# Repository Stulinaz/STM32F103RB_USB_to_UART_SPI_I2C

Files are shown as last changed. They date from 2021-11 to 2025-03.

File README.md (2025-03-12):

<!-- For .md file development refers to https://docs.github.com/en -->
# Stm32 Multiprotocol

> [!IMPORTANT]  
> Firmware rework scheduled by end of April 2025.

### Firmware and Kicad project for my USBtoUART/SPI/I2C converter.

Based on the popular microcontroller ***STM32F103RBT6*** and a custom PCB board.
This project is an embedded software/hardawe solutions that allows you to transfer data from USB to all the main digital interfaces - UART, I2C and SPI.
This board will help you to analyze and debug all the main digital and analog IC’s as well as lot of IOT and RF demoboard, saving you the time to develop a custom firmware
, or buying expensive data converters.

## Board Overview

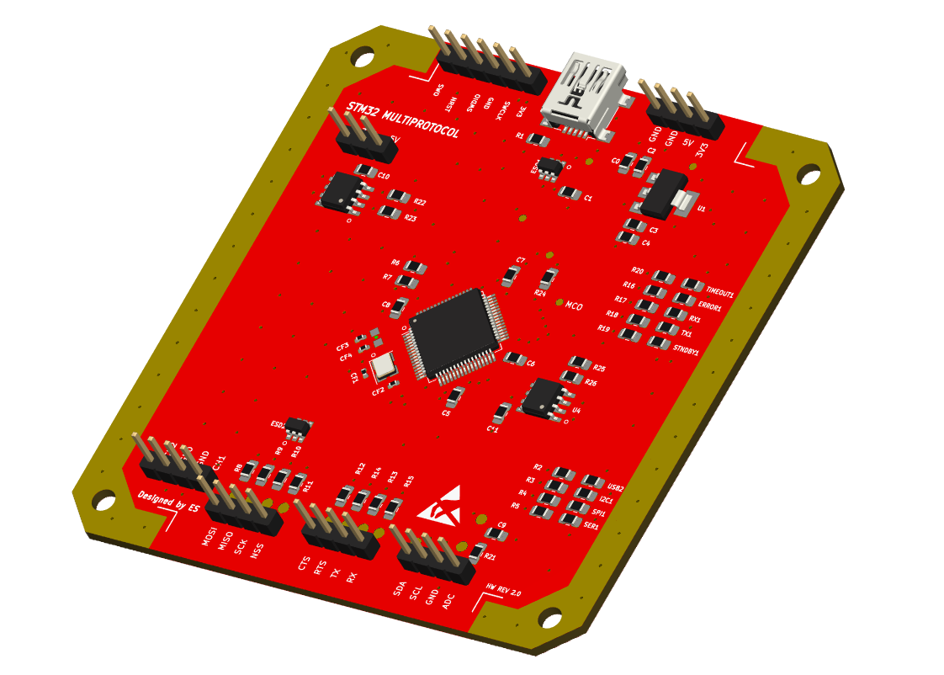
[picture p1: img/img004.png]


## Top Side of the board

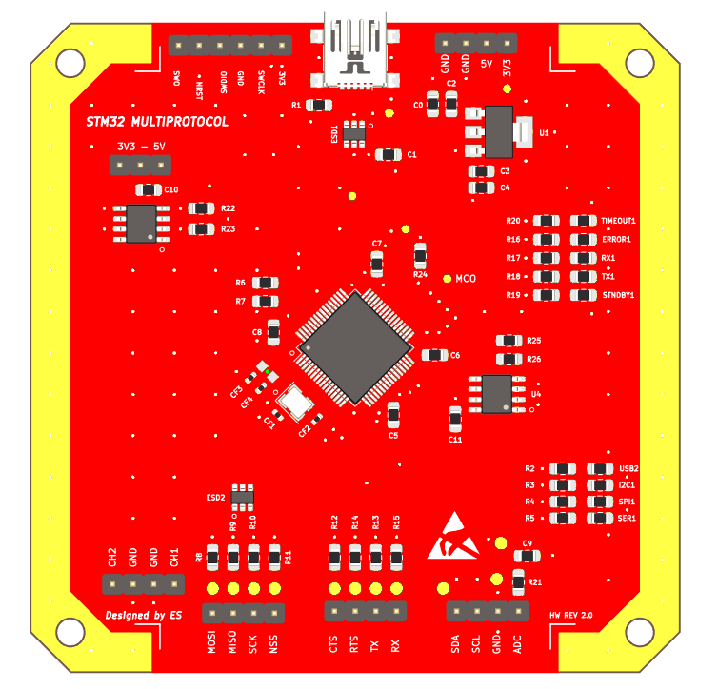
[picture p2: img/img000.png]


## Bottom Side of The board

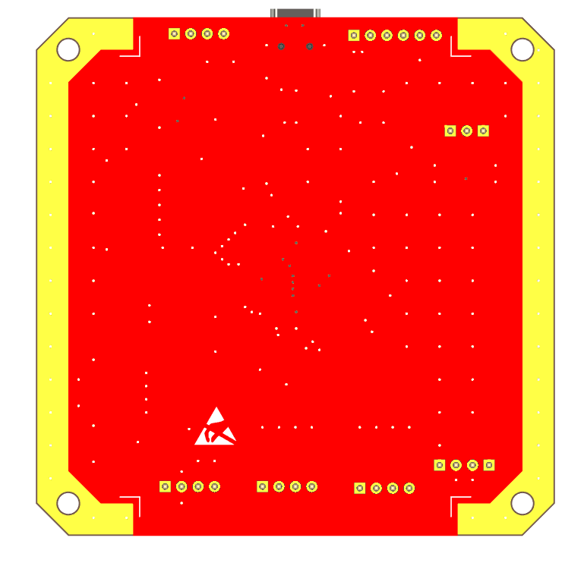
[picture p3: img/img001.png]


## Features 

- SWD Interface.
- Mini USB Connector with ESD protection.
- Power mosfet.
- On board 64k (24C64) eeprom for data storage.

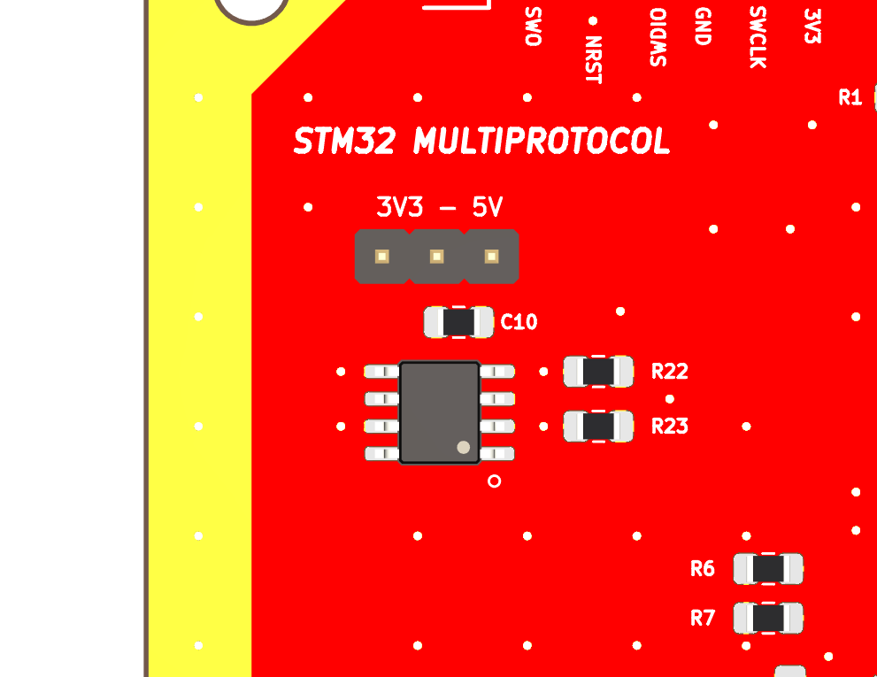
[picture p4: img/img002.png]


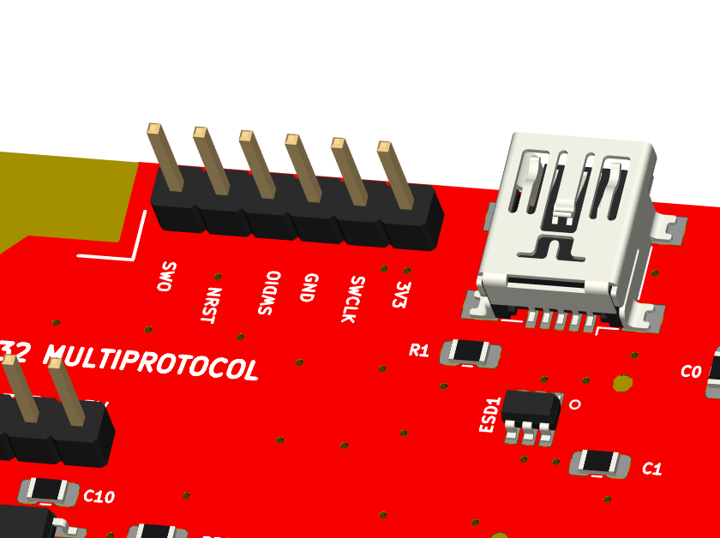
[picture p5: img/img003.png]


## Bill of Materials

| Component  | Description | Part Number | Digy |
|:---  |:--- |:--- |:--- |
| USB1 | CONN RCPT USB2.0 MINI SMD R/A | 0675031020 | [WM5461CT-ND](https://www.digikey.it/it/products/detail/molex/0675031020/1624424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) |
| ESD1 | TVS DIODE 5.25V 17V STO23-6 | USBLC6-2SC6 | [497-5235-6-ND](https://www.digikey.it/it/products/detail/stmicroelectronics/USBLC6-2SC6/1040559) |
| ESD2 | TVS DIODE 5V SOT23-6] | ESDA6V1BC6 | [497-6635-1-ND](https://www.digikey.it/it/products/detail/stmicroelectronics/ESDA6V1BC6/1037985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) |
| U1 | Linear Voltage Regulator IC | IC REG 3.3V 1A | [576-1172-ND](https://www.digikey.it/it/products/detail/microchip-technology/MIC39100-3-3WS/771641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) |
| U2 | ic mcu 32 bit 128kb flash 64LQFP | STM32F103RBT6 | [497-6066-ND](https://www.digikey.it/it/products/detail/stmicroelectronics/STM32F103RBT6/1646341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) |
| Y2 | CRYSTAL 16.0000MHZ 4PF SMD | ABM8W-16.0000MHZ-4-B1U-T3| [535-14020-1-ND](https://www.digikey.it/it/products/detail/abracon-llc/ABM8W-16-0000MHZ-4-B1U-T3/7172791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) |
| U3 | IC GATE DRVR LOW-SIDE 8SOIC | MIC4427ZM | [576-3513-5-ND](https://www.digikey.it/it/products/detail/microchip-technology/MIC4427ZM/1029913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) |
| U4 | IC GATE DRVR LOW-SIDE 8SOIC | M24C64 | [497-14427-1-ND](https://www.digikey.it/it/products/detail/stmicroelectronics/M24C64-DRMN3TP-K/4729231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) | 

## Software needed for development

- [STM32CubeIDE](https://www.st.com/en/development-tools/stm32cubeide.html) **1.17.0**
- [KICAD](https://www.kicad.org/) **8.0.5,release build - 64 bit**
- [GIT](https://git-scm.com/) **2.46.1.windows.1**

## Tools needed for development

Programmer [STLINK](https://www.st.com/en/development-tools/st-link-v2.html)

## Closeup

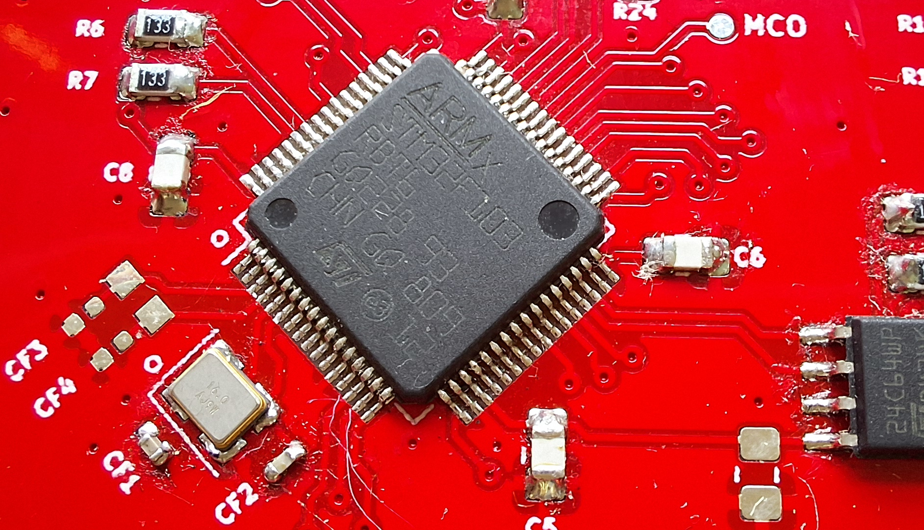
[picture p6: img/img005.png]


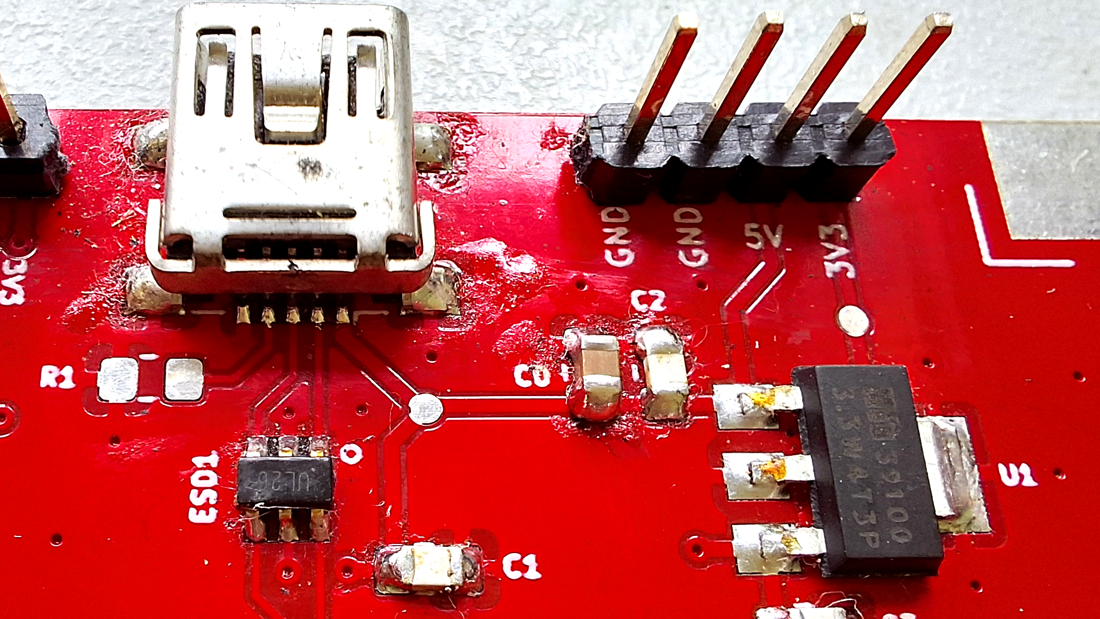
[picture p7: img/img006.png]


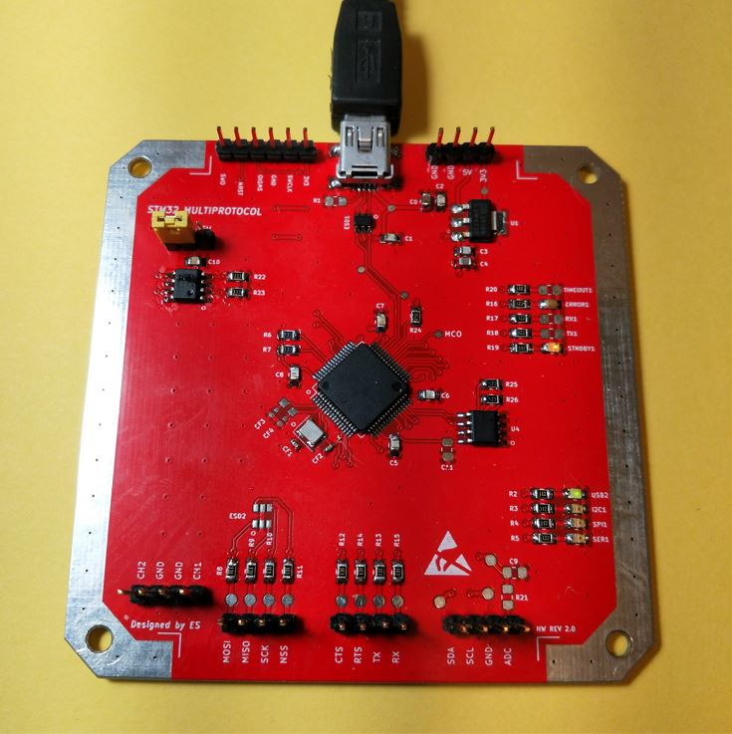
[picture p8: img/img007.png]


## Electrical Characteristics

| **Parameter** | **Min** | **Typ** | **Max** | **Unit** | **Condition/Notes** |
|---|---|---|---|---|---|
| Input Voltage | 4.5 | 5.0 | 5.5 | V | |
| Current Consumption | | 13 | 20 | mA | |

## License

| Component | Copyright | License |
|:--- |:--- |:--- |
| CMSIS | ARM Limited | Apache-2.0 |
| CMSIS Device | ARM Limited - STMicroelectronics | Apache-2.0 |
| STM32WL HAL | STMicroelectronics | BSD-3-Clause |
| FreeRTOS kernel | Amazon.com, Inc. or its affiliates | MIT |
| Stm32 Multiprotocol | N/A | BSD-3-Clause |

## Contact

***enrico.stulin@gmail.com***

[LinkedIn](https://www.linkedin.com/in/enrico-stulin-14090b146/)

## Important Information

> [!CAUTION]
> Manual soldering of SMD components requires high level of manual skills.
> Project not suited for beginners in firmware development.
> A good understanding of C language is a must.

> [!CAUTION]
> This project is provided "AS IS" with no warranties.

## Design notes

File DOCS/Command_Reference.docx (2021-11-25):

Command | Description | NOTE
<stm–h> | Help me! (print all the commands)
<stm–s> | Enables UART interface. Every data will be forwarded to uart interface, enter <stm–a> for closing interface. RESPONSE SUCCESS: “Serial interface selected” RESPONSE INVALID: “unknown command”
<stm–i> | Enables I2C interface. RESPONSE SUCCESS: “I2C interface selected” RESPONSE INVALID: “unknown command”
<stm–p> | Enables SPI interface. Every data will be forwarded to spi interface, enter <imx –a> for closing interface. RESPONSE SUCCESS: “SPI interface selected” RESPONSE INVALID: “unknown command”
<stm–a> | Close the communication interface previosly selected with <stm–s> <stm–i> <stm–p>. RESPONSE SUCCESS: “XXX interface closed” RESPONSE INVALID1: “unknown command”
<stm–testled> | Turns on all on board leds for 10seconds. RESPONSE SUCCESS: “No Response” RESPONSE INVALID1: “unknown command”
<ser–bX> | Baudrate selections for UART interface: X=0 , baudrate 1200 X=1 , baudrate 4800 X=2 , baudrate 9600 X=3 , baudrate 19200 X=4 , baudrate 19200 X=5 , baudrate 19200 X=6 , baudrate 19200 Default or wrong parameter: 9600 RESPONSE SUCCESS: “Serial baudrate set” RESPONSE INVALID1: “unknown command” RESPONSE INVALID2: “Error – interface must be closed”
<spi–nssh> | Set SPI NSS pin active high. Default: NSS active low. RESPONSE SUCCESS: “SPI NSS active high” RESPONSE INVALID1: “unknown command”
<spi–nssl> | Set SPI NSS pin active low. Default: NSS active low. RESPONSE SUCCESS: “SPI NSS active low” RESPONSE INVALID1: “unknown command”
<spi –sX> | Clock speed for spi: X=0 , 6 Mhz X=1 , 3 Mhz X=2 , 1.5 Mhz X=3 , 750 khz X=4 , 357 kHz X=5 , 187 khz X=6 , 93 kHz X=6 , 46 kHz Default or wrong parameter: 46 kHz RESPONSE SUCCESS: “Spi parameter set” RESPONSE INVALID1: “unknown command” RESPONSE INVALID2: “wrong parameter” RESPONSE INVALID2: “Error – interface must be closed”
<spi–cl> | Clock to 0 when idle RESPONSE SUCCESS: “Spi parameter set” RESPONSE INVALID1: “unknown command”
<spi–cl> | Clock to 1 when idle RESPONSE SUCCESS: “Spi parameter set” RESPONSE INVALID1: “unknown command”
<i2c–a0xXX> | Set Slave address. RESPONSE SUCCESS: “Slave Address set” RESPONSE INVALID1: “unknown command”
<i2c–mt> | Generation of Start/repeat start condition + address will be send in write mode. RESPONSE SUCCESS: “Sending address in write mode” RESPONSE INVALID: “unknown command”
<i2c–mr> | Generation of Start/repeat start condition + address will send in read mode. RESPONSE SUCCESS: “Sending address in read mode” RESPONSE INVALID: “unknown command”
<i2c–w0xXX> | Byte Write request. XX value in hexadecimal format [00 – FF] RESPONSE SUCCESS: “Byte write enqueued” RESPONSE INVALID: “unknown command”
<i2c–r> | Byte read request. RESPONSE SUCCESS: “Byte read enqueued” RESPONSE INVALID: “unknown command”
<i2c –q> | Get i2c commands in the queue. RESPONSE SUCCESS: Output the i2c commands queue RESPONSE INVALID: “unknown command”
<i2c –d> | Delete all i2C commands in the queue. SUCCESS: “Queue free” RESPONSE INVALID: “unknown command”
<i2c –x> | Starts i2c transfer. RESPONSE SUCCESS: “Transfer Success” + byte read in HEX format if present. RESPONSE INVALID: “Transfer Failure” + ERROR

REVISION HISTORY
VERSION | REVISION DATE | COMMENTS
1 | 25/22/2021 | First Release

Maker: Stulin Enrico - enrico.stulin@gmail.com – 04/06/2021

STM32 MULTIPROTOCOL

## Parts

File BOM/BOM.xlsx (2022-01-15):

COMPONENT | PART NUMBER | DESCRIPTION | QTY | DIGIKEY ORDER CODE
U1 | MIC39100-3.3WS | Linear Voltage Regulator IC Positive Fixed 1 Output 1A SOT-223-3 | 1 | 576-1172-ND
U2 | STM32F103RBT6 | ic mcu 32 bit 128kb flash 64LQFP | 1 | 497-6066-ND
U3 | MIC4427ZM | IC GATE DRVR LOW-SIDE 8SOIC | 1 | 576-3513-5-ND
U4 | M24C64-DRMN3TP/K | IC EEPROM 64KBIT I2C 1MHZ 8SO | 1 | 497-14427-1-ND
ESD1 | USBLC6-2SC6 | TVS DIODE 5.25V 17V STO23-6 | 1 | 732-1077-1-ND
ESD2 | ESDA6V1BC6 | TVS DIODE 5V SOT23-6 | 1 | 497-6635-1-ND
Y2 | ABM8W-16.0000MHZ-4-B1U-T3 | CRYSTAL 16.0000MHZ 4PF SMD | 1 | 535-14020-1-ND
USB1 | 675031020 | CONN RCPT USB2.0 MINI SMD R/A | 1 | WM5461CT-ND
R1 | CRCW0805100KDHEAP | RES SMD 100K OHM 5% 1/8W 0805 | 1 | 541-100KAZCT-ND
R2, R3, R4, R5, R16, R17, R18, R19, R20 | RMCF0805JT1K00 | RES 1k OHM 5% 1/8W 0805 | 9 | RMCF0805JT1K00CT-ND
R6, R7, R22, R23, R25, R26 | CR0805-JW-103ELF | RES SMD 10k OHM 5% 1/W 0805 | 6 | CR0805-JW-103ELFCT-ND
R8, R9, R10, R11, R12, R13, R14, R15 | CR0805-JW-101ELF | RES SMD 100 OHM 5% 1/W 0805 | 8 | CR0805-JW-101ELFCT-ND
R21 | CR0805-J/-4R7ELF | RES SMD 4.7 OHM 5% 1/8W 0805 | 1 | CR0805-J/-4R7ELF
R24 | CR0805-JW-152ELF | RES SMD 1.5K OHM 5% 1/8W 0805 | 1 | 118-CR0805-JW-152ELFCT-ND
C0, C1, C4, C5, C6, C7, C8, C10, C11 | C0805C101K8RAC7800 | CAP CER 100PF 10V X7R 0805 | 9 | 399-15004-1-ND
C3, C9 | C0805C106K4PAC7800 | CAP CER 10UF 16V X5R 0805 | 2 | 399-C0805C106K4PAC7800CT-ND
C2 | GRM21BR71C105KA01L | CAP CER 1UF 16V X7R 0805 | 1 | 490-1691-1-ND
CF1, CF2 | 04025A3R3BAT2A | CAP CER 3.3PF 50V NP0 0402 | 2 | 478-10103-1-ND
LED GREEN | LG R971-KN-1 | LED GREEN DIFFUSED 0805 SMD | 10 | 475-1410-1-ND
LED RED | LH R974-LP-1-0-20-R18 | LED RED DIFFUSED 0805 SMD | 10 | 475-LHR974-LP-1-0-20-R18CT-ND
LED ORANGE | LO R976-PS-1 | LED ORANGE DIFFUSED 0805 SMD | 10 | LO R976-PS-1
CF3, CF4 | NM | NM | NM | NM
CONNECTORS | 1-87220-0 | CONN HEADER VERT 10POS 2.54MM | 5 | A26556-ND

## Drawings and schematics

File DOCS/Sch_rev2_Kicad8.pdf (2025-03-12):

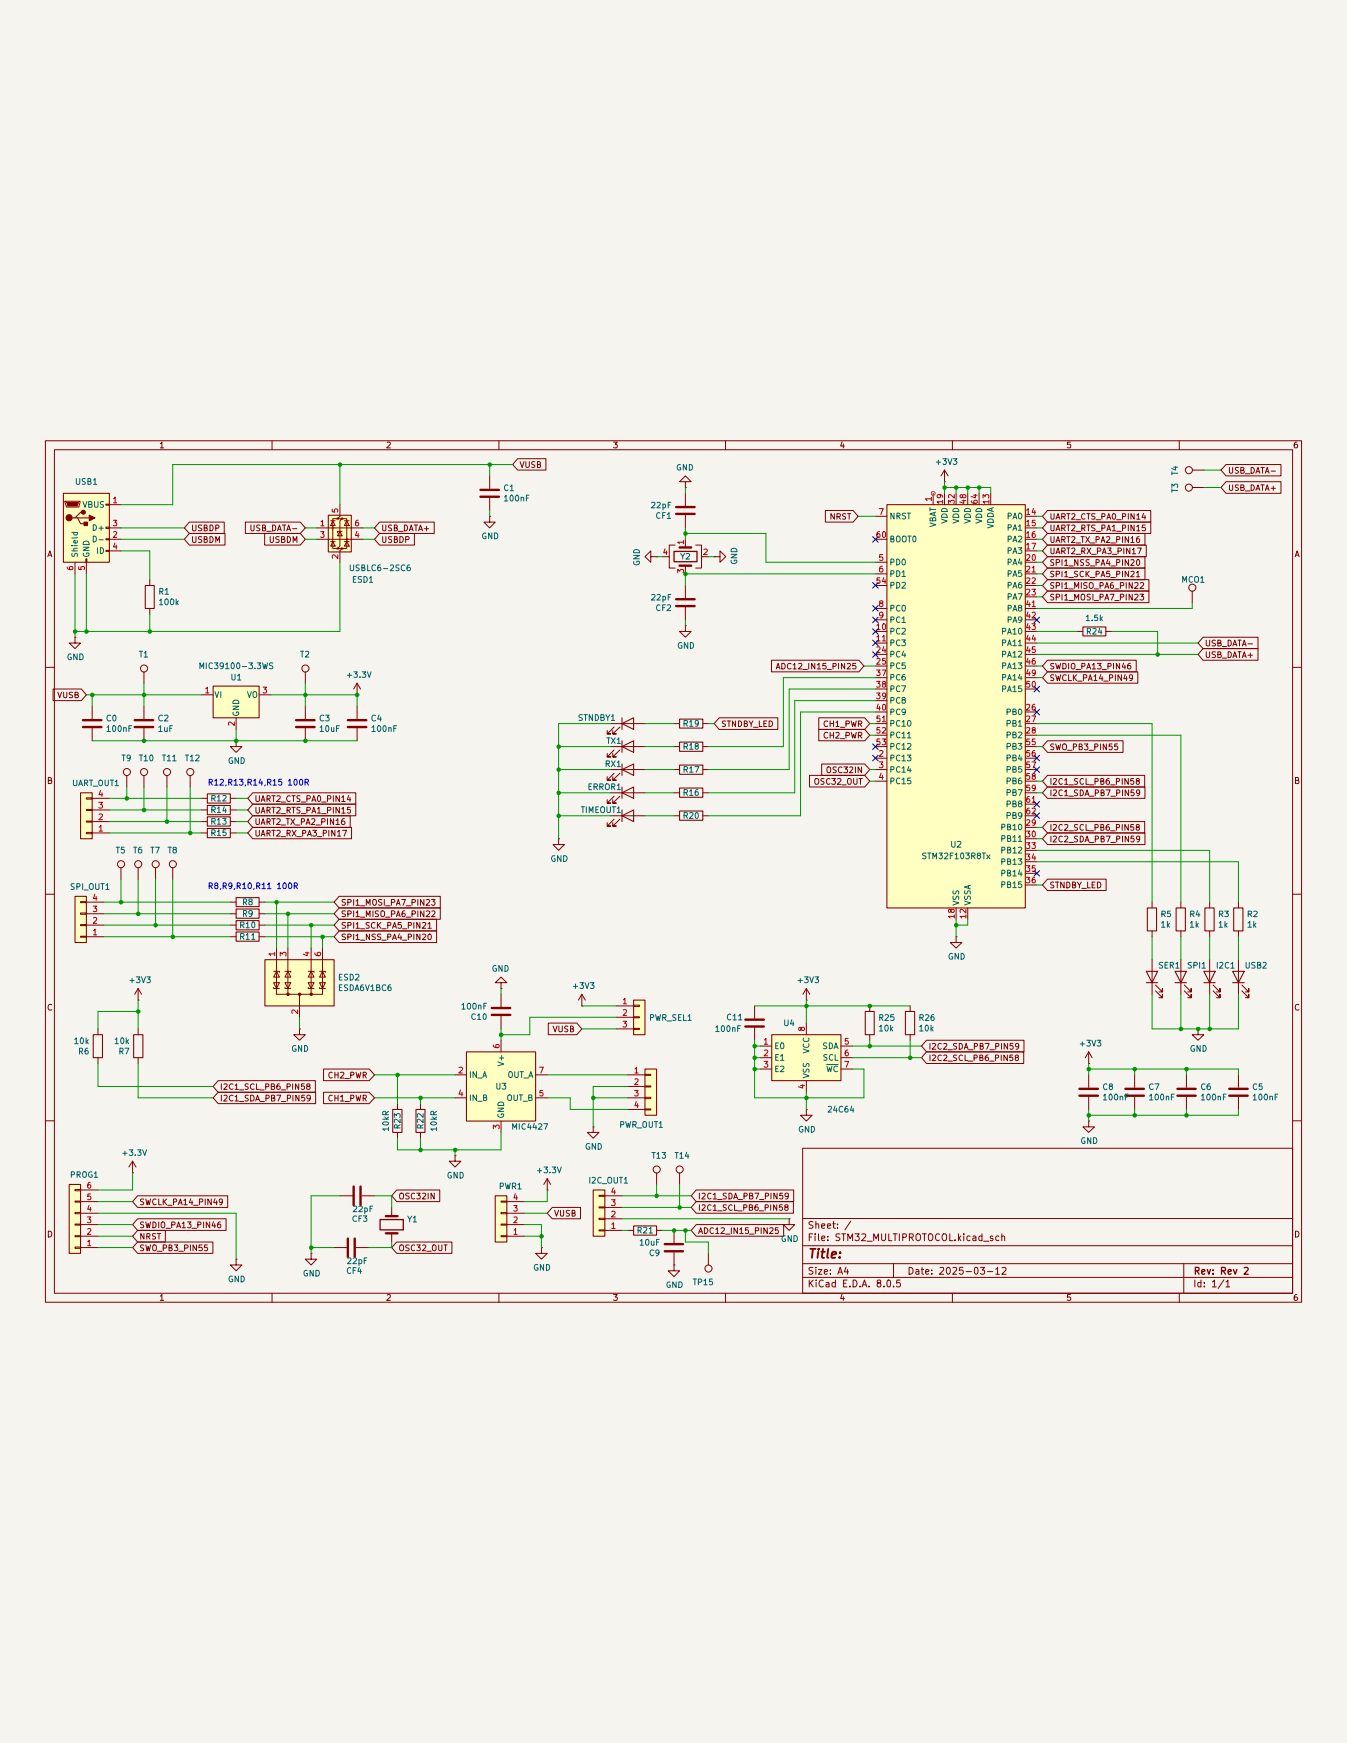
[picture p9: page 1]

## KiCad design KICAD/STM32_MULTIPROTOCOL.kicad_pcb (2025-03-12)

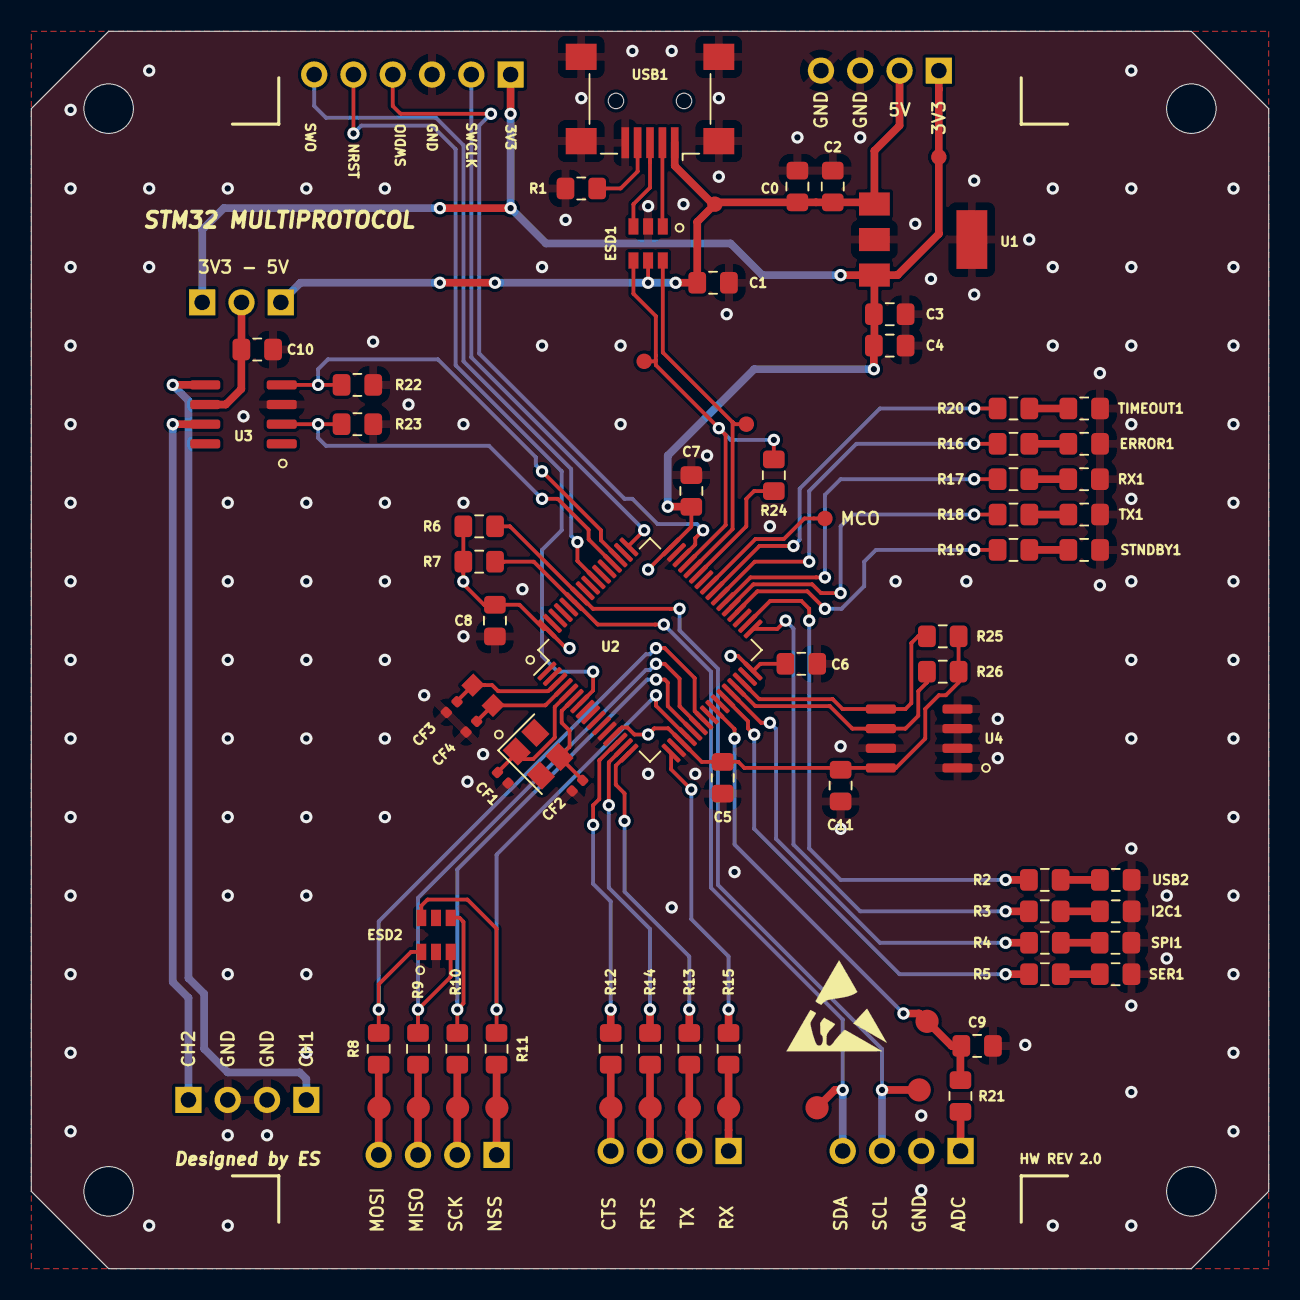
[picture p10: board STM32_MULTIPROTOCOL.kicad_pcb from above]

Board: 2 copper layers, 80.0 x 80.0 mm, 83 parts (0 on the bottom side), 63 nets.

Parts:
C0, C1, C4, C5, C6, C7, C8, C10, C11: 100nF; R_0805_2012Metric_Pad1.15x1.40mm_HandSolder
C2: 1uF; R_0805_2012Metric_Pad1.15x1.40mm_HandSolder
C3, C9: 10uF; R_0805_2012Metric_Pad1.15x1.40mm_HandSolder
CF1, CF2, CF3, CF4: 22pF; R_0402_1005Metric
ERROR1: LED; R_0805_2012Metric_Pad1.15x1.40mm_HandSolder
ESD1: USBLC6-2SC6; SOT-23-6
ESD2: ESDA6V1BC6; SOT-23-6
I2C1: LED; R_0805_2012Metric_Pad1.15x1.40mm_HandSolder
I2C_OUT1: Conn_01x04; PinHeader_1x04_P2.54mm_Vertical
MCO1: TestPoint; TestPoint_Pad_D1.0mm
PROG1: Conn_01x06; PinHeader_1x06_P2.54mm_Vertical
PWR1: Conn_01x04; PinHeader_1x04_P2.54mm_Vertical
PWR_OUT1: Conn_01x04; PinHeader_1x04_P2.54mm_Vertical
PWR_SEL1: Conn_01x03; PinHeader_1x03_P2.54mm_Vertical
R1: 100k; R_0805_2012Metric_Pad1.15x1.40mm_HandSolder
R2, R3, R4, R5: 1k; R_0805_2012Metric_Pad1.15x1.40mm_HandSolder
R6, R7, R25, R26: 10k; R_0805_2012Metric_Pad1.15x1.40mm_HandSolder
R8, R9, R10, R11, R12, R13, R14, R15, R16, R17, R18, R19, R20, R21: 100R; R_0805_2012Metric_Pad1.15x1.40mm_HandSolder
R22, R23: 10kR; R_0805_2012Metric_Pad1.15x1.40mm_HandSolder
R24: 1.5k; R_0805_2012Metric_Pad1.15x1.40mm_HandSolder
RX1: LED; R_0805_2012Metric_Pad1.15x1.40mm_HandSolder
SER1: LED; R_0805_2012Metric_Pad1.15x1.40mm_HandSolder
SPI1: LED; R_0805_2012Metric_Pad1.15x1.40mm_HandSolder
SPI_OUT1: Conn_01x04; PinHeader_1x04_P2.54mm_Vertical
STNDBY1: LED; R_0805_2012Metric_Pad1.15x1.40mm_HandSolder
T1, T2, T3, T4: TestPoint; TestPoint_Pad_D1.0mm
T5, T6, T7, T8, T9, T10, T11, T12, T13, T14: TestPoint; TestPoint_Pad_D1.5mm
TIMEOUT1: LED; R_0805_2012Metric_Pad1.15x1.40mm_HandSolder
TP15: TestPoint; TestPoint_Pad_D1.5mm
TX1: LED; R_0805_2012Metric_Pad1.15x1.40mm_HandSolder
U1: MIC39100-3.3WS; SOT-223-3_TabPin2
U2: STM32F103R8Tx; LQFP-64_10x10mm_P0.5mm
U3: MIC4427; SOIC-8_3.9x4.9mm_P1.27mm
U4: M24C02-WMN; SOIC-8_3.9x4.9mm_P1.27mm
UART_OUT1: Conn_01x04; PinHeader_1x04_P2.54mm_Vertical
USB1: USB_B_Mini; USB_Mini-B_Lumberg_2486_01_Horizontal
USB2: LED; R_0805_2012Metric_Pad1.15x1.40mm_HandSolder
Y1: Crystal; Crystal_SMD_TXC_9HT11-2Pin_2.0x1.2mm_HandSoldering
Y2: Crystal_GND24; Crystal_SMD_3225-4Pin_3.2x2.5mm

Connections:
+3V3: C3.1, C4.1, C5.1, C6.1, C7.1, C8.1, C11.1, PROG1.6, PWR1.4, PWR_SEL1.1, R6.2, R7.2, R25.1, R26.1, T2.1, U1.3, U2.13, U2.19, U2.32, U2.48, U2.64, U4.8
ADC12_IN15_PIN25: C9.2, R21.2, TP15.1, U2.25
CH1_PWR: R22.1, U2.51, U3.4
CH2_PWR: R23.1, U2.52, U3.2
GND: C0.2, C1.2, C2.2, C3.2, C4.2, C5.2, C6.2, C7.2, C8.2, C9.1, C10.2, C11.2, CF1.2, CF2.2, CF3.2, CF4.2, ERROR1.1, ESD1.2, ESD2.2, ESD2.5, I2C1.1, I2C_OUT1.2, PROG1.4, PWR1.1, PWR1.2, PWR_OUT1.2, PWR_OUT1.3, R1.2, R22.2, R23.2, RX1.1, SER1.1, SPI1.1, STNDBY1.1, TIMEOUT1.1, TX1.1, U1.2, U2.12, U2.18, U2.31, U2.47, U2.63, U3.3, U4.1, U4.2, U4.3, U4.4, U4.7, USB1.5, USB1.6, USB2.1, Y2.2, Y2.4
I2C1_SCL_PB6_PIN58: I2C_OUT1.3, R6.1, T14.1, U2.58
I2C1_SDA_PB7_PIN59: I2C_OUT1.4, R7.1, T13.1, U2.59
I2C2_SCL_PB6_PIN58: R26.2, U2.29, U4.6
I2C2_SDA_PB7_PIN59: R25.2, U2.30, U4.5
NRST: PROG1.2, U2.7
unnamed: C10.1, PWR_SEL1.2, U3.6
unnamed: CF1.1, U2.5, Y2.1
unnamed: CF2.1, U2.6, Y2.3
unnamed: ERROR1.2, R16.1
unnamed: I2C1.2, R3.2
unnamed: I2C_OUT1.1, R21.1
unnamed: MCO1.1, U2.41
unnamed: PWR_OUT1.1, U3.7
unnamed: PWR_OUT1.4, U3.5
unnamed: R1.1, USB1.4
unnamed: R2.1, U2.34
unnamed: R2.2, USB2.2
unnamed: R3.1, U2.33
unnamed: R4.1, U2.28
unnamed: R4.2, SPI1.2
unnamed: R5.1, U2.27
unnamed: R5.2, SER1.2
unnamed: R8.1, SPI_OUT1.4, T5.1
unnamed: R9.1, SPI_OUT1.3, T6.1
unnamed: R10.1, SPI_OUT1.2, T7.1
unnamed: R11.1, SPI_OUT1.1, T8.1
unnamed: R12.1, T9.1, UART_OUT1.4
unnamed: R13.1, T11.1, UART_OUT1.2
unnamed: R14.1, T10.1, UART_OUT1.3
unnamed: R15.1, T12.1, UART_OUT1.1
unnamed: R16.2, U2.39
unnamed: R17.1, RX1.2
unnamed: R17.2, U2.38
unnamed: R18.1, TX1.2
unnamed: R18.2, U2.37
unnamed: R19.1, STNDBY1.2
unnamed: R20.1, TIMEOUT1.2
unnamed: R20.2, U2.40
unnamed: R24.1, U2.43
OSC32IN: CF3.1, U2.3, Y1.1
OSC32_OUT: CF4.1, U2.4, Y1.2
SPI1_MISO_PA6_PIN22: ESD2.3, R9.2, U2.22
SPI1_MOSI_PA7_PIN23: ESD2.1, R8.2, U2.23
SPI1_NSS_PA4_PIN20: ESD2.6, R11.2, U2.20
SPI1_SCK_PA5_PIN21: ESD2.4, R10.2, U2.21
STNDBY_LED: R19.2, U2.36
SWCLK_PA14_PIN49: PROG1.5, U2.49
SWDIO_PA13_PIN46: PROG1.3, U2.46
SWO_PB3_PIN55: PROG1.1, U2.55
UART2_CTS_PA0_PIN14: R12.2, U2.14
UART2_RTS_PA1_PIN15: R14.2, U2.15
UART2_RX_PA3_PIN17: R15.2, U2.17
UART2_TX_PA2_PIN16: R13.2, U2.16
USBDM: ESD1.1, USB1.2
USBDP: ESD1.3, USB1.3
USB_DATA+: ESD1.4, R24.2, T3.1, U2.45
USB_DATA-: ESD1.6, T4.1, U2.44
VUSB: C0.1, C1.1, C2.1, ESD1.5, PWR1.3, PWR_SEL1.3, T1.1, U1.1, USB1.1

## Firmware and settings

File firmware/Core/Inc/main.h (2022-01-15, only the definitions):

#define USART_TX_Pin GPIO_PIN_2
#define USART_TX_GPIO_Port GPIOA
#define USART_RX_Pin GPIO_PIN_3
#define USART_RX_GPIO_Port GPIOA
#define SERIAL_LED_Pin GPIO_PIN_1
#define SERIAL_LED_GPIO_Port GPIOB
#define SPI_LED_Pin GPIO_PIN_2
#define SPI_LED_GPIO_Port GPIOB
#define STANDBY_LED_Pin GPIO_PIN_15
#define STANDBY_LED_GPIO_Port GPIOB
#define TX_LED_Pin GPIO_PIN_6
#define TX_LED_GPIO_Port GPIOC
#define RX_LED_Pin GPIO_PIN_7
#define RX_LED_GPIO_Port GPIOC
#define ERROR_LED_Pin GPIO_PIN_8
#define ERROR_LED_GPIO_Port GPIOC
#define TIMEOUT_LED_Pin GPIO_PIN_9
#define TIMEOUT_LED_GPIO_Port GPIOC
#define USB_ENABLE_Pin GPIO_PIN_10
#define USB_ENABLE_GPIO_Port GPIOA
#define DRIVER_CH1_Pin GPIO_PIN_10
#define DRIVER_CH1_GPIO_Port GPIOC
#define DRIVER_CH2_Pin GPIO_PIN_11
#define DRIVER_CH2_GPIO_Port GPIOC
#define I2C_LED_Pin GPIO_PIN_10
#define I2C_LED_GPIO_Port GPIOB
#define USB_LED_Pin GPIO_PIN_11
#define USB_LED_GPIO_Port GPIOB
#define EEPROM_IIC_SDA_PIN  GPIO_PIN_11
#define EEPROM_IIC_SDA_PORT GPIOB
#define EEPROM_IIC_SCL_PIN  GPIO_PIN_10
#define EEPROM_IIC_SCL_PORT GPIOB
#define I2C_LED_Pin GPIO_PIN_12
#define I2C_LED_GPIO_Port GPIOB
#define USB_LED_Pin GPIO_PIN_13
#define USB_LED_GPIO_Port GPIOB
#define UART_TX_PIN GPIO_PIN_2
#define UART_TX_PORT GPIOA
#define UART_RX_PIN GPIO_PIN_3
#define UART_RX_PORT GPIOA
#define UART_CTS_PIN GPIO_PIN_0
#define UART_CTS_PORT GPIOA
#define UART_RTS_PIN GPIO_PIN_1
#define UART_RTS_PORT GPIOA
#define SPI_PORT GPIOA
#define SPI_NSS_PIN GPIO_PIN_4
#define SPI_MISO_PIN GPIO_PIN_6
#define SPI_MOSI_PIN GPIO_PIN_7
#define SPI_SCK_PIN GPIO_PIN_5
#define IIC_PORT GPIOB
#define IIC_SDA_PIN GPIO_PIN_7
#define IIC_SCL_PIN GPIO_PIN_6
#define NUL 0
#define TIMEOUT 2
#define PASS    1
#define FAIL    0

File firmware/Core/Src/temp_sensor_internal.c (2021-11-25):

#include "temp_sensor_internal.h"

ADC_HandleTypeDef hadc1;

HAL_StatusTypeDef TempSensorInit(void)
{
  ADC_ChannelConfTypeDef sConfig = {0};
  hadc1.Instance                   = ADC1;
  hadc1.Init.ScanConvMode          = ADC_SCAN_DISABLE;
  hadc1.Init.ContinuousConvMode    = DISABLE;
  hadc1.Init.DiscontinuousConvMode = DISABLE;
  hadc1.Init.ExternalTrigConv      = ADC_SOFTWARE_START;
  hadc1.Init.DataAlign             = ADC_DATAALIGN_RIGHT;
  hadc1.Init.NbrOfConversion       = 1;
  if (HAL_ADC_Init(&hadc1) != HAL_OK)
	  return HAL_ERROR;

  sConfig.Channel      = ADC_CHANNEL_TEMPSENSOR;
  sConfig.Rank         = ADC_REGULAR_RANK_1;
  sConfig.SamplingTime = ADC_SAMPLETIME_1CYCLE_5;
  if (HAL_ADC_ConfigChannel(&hadc1, &sConfig) != HAL_OK)
	  return HAL_ERROR;
  return HAL_OK;
}

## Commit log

2021-11-24 uart,spi,iic pins init in input mode. USB enable fixed.
    [STM32_MULTIPROTOCOL.kicad_pcb, STM32_MULTIPROTOCOL.sch]
2021-11-25 added command "stm-testled" for soldering, added schematic.pdf
    [STM32_MULTIPROTOCOL.sch]
2021-11-25 added tim 4 and command reference.docx, fixed app_usb
    [STM32_MULTIPROTOCOL.ioc, app.c, app_usb.c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]
2021-11-25 added detailed BOM of the boards
    [BOM.xlsx, STM32_MULTIPROTOCOL.kicad_pcb, STM32_MULTIPROTOCOL.sch]
2021-11-29 added driver for MIPOT TRX module 32001270/32001534
2021-12-20 tx/rx led fixed, uart rx data streming fixed
    [32001279_32001534.c, app.c, buffers_manager.c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]
2022-01-11 added pcb revision 2, fixed firmware project for cloners
    [BOM_rev1.xlsx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]
2022-01-15 added rev 2 BOM, added driver for onboard 24C64 eeprom, improved app_usb
    [BOM_rev2.xlsx, STM32_MULTIPROTOCOL.sch]
2022-01-15 added contact for information and samples
2022-01-20 device reads and store its uptime in eeprom
2022-02-11 improved power consumption, developing driver for oled display SSD1306
2022-03-03 ssd1306 driver is working, improved power consumption
2025-03-11 directory redefined, scheduled fw rework
    [STM32_MULTIPROTOCOL-B_Cu.gbl, STM32_MULTIPROTOCOL-B_Mask.gbs, STM32_MULTIPROTOCOL-B_SilkS.gbo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]
2025-03-12 updated to kicad 8
    [STM32_MULTIPROTOCOL.kicad_pcb, STM32_MULTIPROTOCOL.kicad_sch, STM32_MULTIPROTOCOL.sch]
2025-03-12 added contact information - removed rev 1
    [BOM.xlsx, BOM_rev1.xlsx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]

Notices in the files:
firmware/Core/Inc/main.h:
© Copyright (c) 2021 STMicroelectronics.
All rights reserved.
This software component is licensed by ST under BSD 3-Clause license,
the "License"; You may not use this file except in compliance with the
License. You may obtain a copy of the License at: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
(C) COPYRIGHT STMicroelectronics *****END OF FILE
